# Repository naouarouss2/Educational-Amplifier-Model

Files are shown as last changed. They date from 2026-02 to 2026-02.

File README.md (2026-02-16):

# Educational Amplifier Model
## What is it ? 📔
This is a model used to teach students about the working principle of a integrated linear amplifier.
## Features ✅
-  3 1KOhm resistors
-  2 2KOhm resistors
-  1 3KOhm resistor
-  2 5KOhm resistors
-  2 10KOhm resistors.
-  2 100 nF non-polarized capacitors
-  10K Potentiometer
-  TL081 Amplifier IC
## Why did I make it ? 🛠️
My electrical engineering teacher had some models provided by the ministry of education. But they had tiny 2mm banana terminals, and were very ugly-looking with a low quality PCB on top, mounted on a cheap electrical box.

When I showed him a project I made before, using laser-cut and engraved MDF wood, he asked me to partener up with him and make a new, better-looking, more functional model, with 4mm banana temrinals.
## CAD
Really just the top plate.



For the box my teacher gave me, it is 301*201mm (outside dimensions), and the wall thickness is 13.5mm.

## Wiring diagram 🔌
It is pretty self explanatory on the top face with the symbols.

But here is the diagram for the amplifier IC.



The top power terminals are left unconnected. They are just there to position the power inputs directly on the model, instead of pulling a lot of wires directly from the PSU.
## Finished product 💎

20260129_114559 (2)

## License 🔓
This project is put opensource.

Building as is, is allowed.

Remixing is also allowed, as long as the original project is linked and credited.
## Credits ❤️
Made by **Oussama NAOUAR**

Total logged working time : ~26.4hrs

Made for Ariana's Pioneer High School (LPA).
## BOM 💵

|Component Name |Description |Link |Unit Price|Product Amount|Total Price|
|---|---|---|---|---|---|
|Blue 4mm Banana Secure Terminals  |4mm diameter banana terminal |https://www.celectronix.com/banane/962-fiche-banane-femelle-4mm-bleu-avec-securit-.html |0,52 |22 |11,44 |
|Black 4mm Banana Secure Terminals |4mm diameter banana terminal |https://www.celectronix.com/banane/966-fiche-banane-femelle-4mm-noire-avec-securit-.html|0,52 |2 |1,04 |
|Red 4mm Banana Secure Terminals |4mm diameter banana terminal |https://www.celectronix.com/banane/968-fiche-banane-femelle-4mm-rouge-avec-securit-.html|0,52 |3 |1,56 |
|Green 4mm Banana Secure Terminals |4mm diameter banana terminal |https://www.celectronix.com/banane/970-fiche-banane-femelle-4mm-vert-avec-securit-.html |0,52 |6 |3,12 |
|Yellow 4mm Banana Secure Terminals|4mm diameter banana terminal |https://www.celectronix.com/banane/964-fiche-banane-femelle-4mm-jaune-avec-securit-.html|0,52 |2 |1,04 |
|10KOhm potentiometer |Rotating 10KOhm potentiometer |https://tuni-smart-innovation.com/products/potentiometre-10k?_pos=3&_sid=f3b0b5077&_ss=r|0,52 |1 |0,52 |
|100nF Capacitors |Non-polarized 100nF capacitor |https://cothings.net/products/condensateur-en-ceramique-104100nf-50v |0,035 |2 |0,07 |
|TL081 Amplifier IC |The heart of the project; The amplifier itself|https://es-online.tn/produit/tl081cp-amplificateur-operationnel-jfet-monocanal-dip-8 |1,19 |1 |1,19 |
|Thin wire |Used to wire everything up |N/A; I already have some |0 |About 2-3m |0 |
|Laser-cut top plate |The plate on which everything was mounted |N/A |7,34 |1 |7,34 |
| | | | |GRAND TOTAL |27,32 |

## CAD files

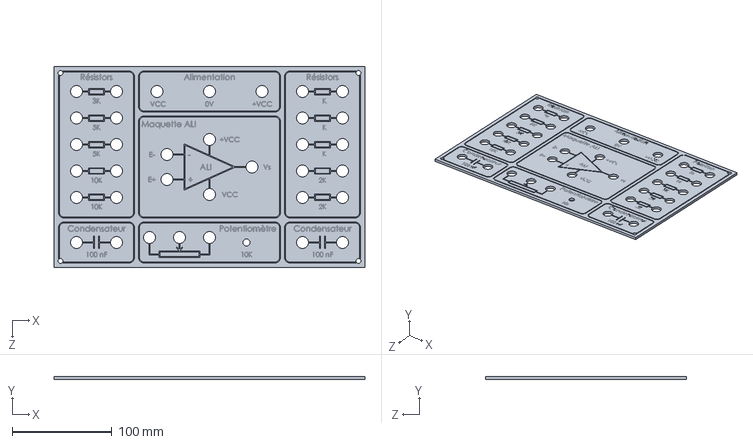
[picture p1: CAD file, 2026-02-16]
CAD/Top.STEP
311.0 x 3.00 x 201.0 mm

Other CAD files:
CAD/TOP.SLDPRT
CAD/Top.DXF

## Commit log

2026-01-21 Add README
    [Top.STEP]
2026-02-03 Update README with BOM details and images
    Updated the BOM section and added images of the finished product. Changed 'IC' to 'TL081 Amplifier IC' for clarity.
2026-02-16 Update README with amplifier IC diagram and notes
    Added diagram for the amplifier IC and clarified power terminal connections.
2026-02-16 Add new image to CAD section in README
    Added an additional image to the CAD section.
